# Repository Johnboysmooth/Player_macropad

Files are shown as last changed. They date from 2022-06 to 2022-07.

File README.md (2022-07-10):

# Player! V1.2

Player! is a five button macropad originally designed to accomodate changing music settings in Spotify without tabbing into the Spotify client. By default it is programmed to use the built-in media keys in Windows, which can be further optimised with global hotkeys using [Toastify](https://github.com/aleab/toastify).

Using four cherry compatible switches, Player! provides dedicated keys for pausing/playing music -  returning to a previous song, and skipping to the next song. The fourth switch remains user programmable, binded to 'insert' by default to be used as dedicated Discord mute key. A rotary encoder allows for volume control, with a toggle function bound to its embedded switch to allow rotary control of rewinding and fast-forwarding music.
# Images
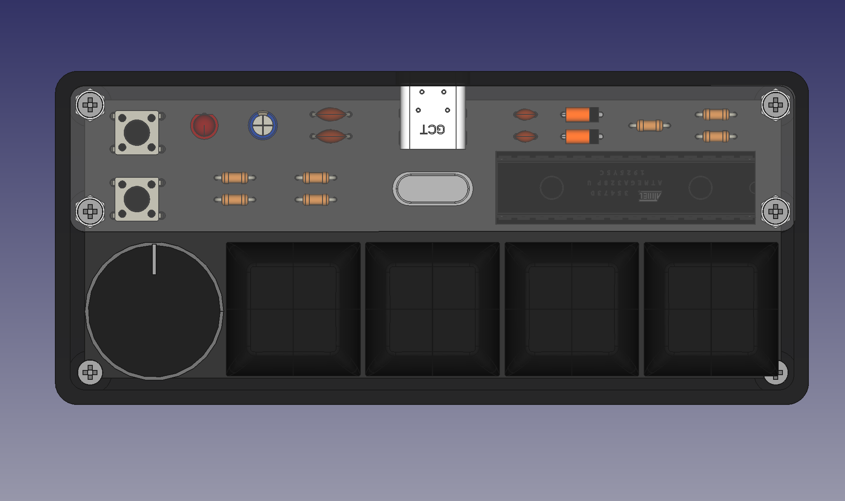
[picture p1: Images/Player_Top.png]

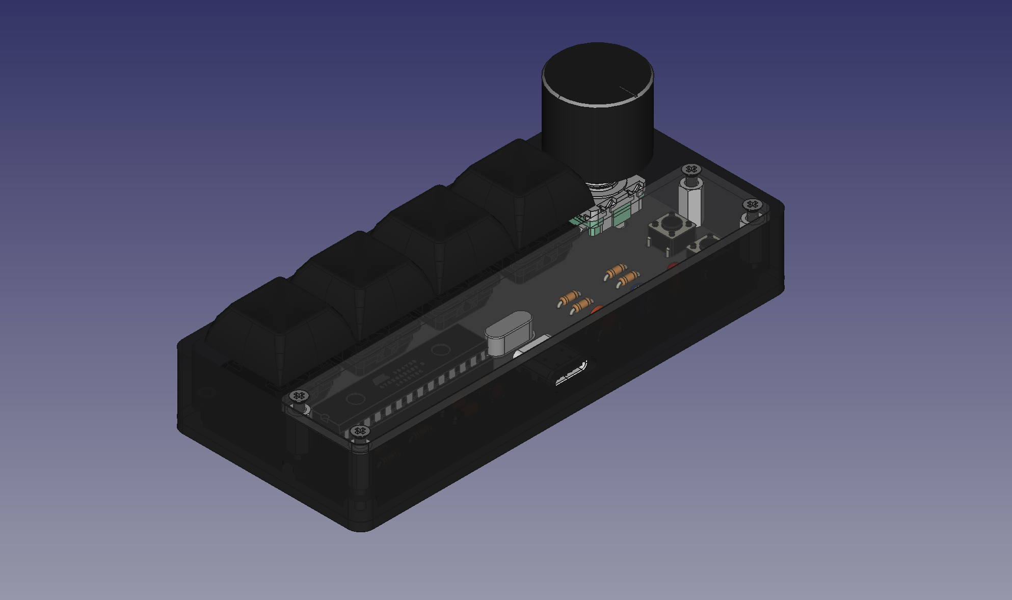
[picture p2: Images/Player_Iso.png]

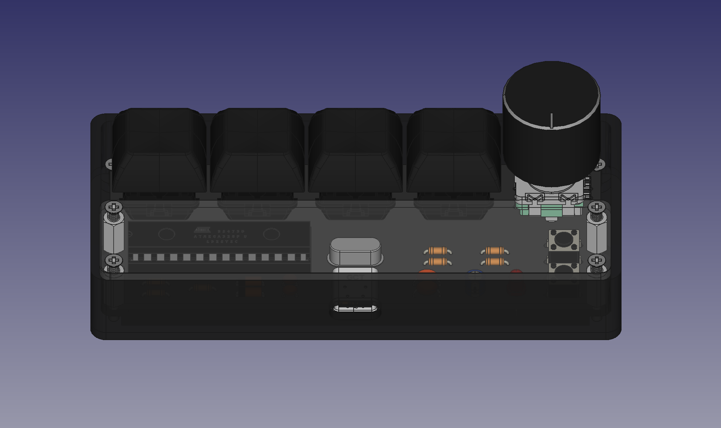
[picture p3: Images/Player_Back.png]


# [Bill of Materials](https://octopart.com/bom-tool/iGNVRgwb)

# Bootloader Information

The Player! uses a usb bootloader which allows the ATMega328 to program itself with QMK, namely USBaspLoader.

The custom bootloader was adapted from [coseyfannitutti](https://github.com/coseyfannitutti)'s, changing a few pin definitions, programmer choice and adding a port definiton for avrdude in my setup. 

* The bootloader is available [here](https://github.com/Johnboysmooth/USBaspLoader).
* The instructions for setting up the build environment can be found in the readme.
* Some changes may be required, such as changing the port or programmer definitions for your setup, which can be found on lines 9 and 44 of the makefile.inc respectively. **Never** edit the makefile directly.
* Flashing the ATMega328 once the build environment is setup:

	```make flash``` (flashes the makefile)

	```make fuse``` (sets fuses for ATMega328)

Assuming the flash was successful, it should now be possible to return the microcontroller to the Player! PCB and flash the firmware via the USB connection.

# Firmware 
Player! supports either [Vial](https://get.vial.today/) or [VIA](https://www.caniusevia.com/) for rebinding keys. It is recommended to use Vial to allow rebinding of the rotary encoder, and avoid additional steps required in VIA.

### Entering bootloader mode
Player! will need to be put into bootloader mode to allow QMK to be flashed via the USB connection, see below:

1. Press and hold ```Boot``` switch
2. Tap ```Reset``` switch
3. Release ```Boot``` switch

USBaspLoader will show up in device manager or as a connected device in QMK toolbox when the device has successfully entered bootloader mode, like so:
![](/Images/QMK_Toolbox.png)

## Vial Support (Recommended)

Vial compatible firmware can be flashed to the Player! using the [player_vial.hex](/Firmware). 
1. In QMK_Toolbox, click "Open", then navigate to player_vial.hex and select it. 
2. Click "Flash". 
3. Following successful flash completion, press the ```Reset``` button on the PCB. 

The Player! can now be configured and is now ready to use. The rotary encoder is rebound using the two circular icons on the top row.

*A current bug means the second layer is incorrectly labelled, however it maintains functionality.

### VIA Support (Not Recommended)

VIA compatible firmware can also be flashed to the Player! using the [player_via.hex](/Firmware), however an additional step is required.
1. In QMK_Toolbox, click "Open" then navigate to player_vial.hex and select it.
2. Click "Flash". 
3. Following successful flash completion, press the ```Reset``` button on the PCB. 
4. After opening the VIA window, navigate to the "Design" tab (which may require enabling in settings) and upload the playerkeymap.json. 

Going back to the Configure tab in VIA, the Player! can be configured and is now ready to use.

### Default Configuration

It is not required to use Vial or VIA when using the Player!, the default keymap can be flashed using the [player_default.hex](/Firmware). 
1. In QMK_Toolbox, click "Open" and navigate to player_default.hex and click "Flash".
2. Following successful flash completion, press the ```Reset``` button on the PCB. 

The Player! is now ready to use.

## License
<br />Player! is licensed under a <a rel="license" href="http://creativecommons.org/licenses/by-nc/4.0/">Creative Commons Attribution-NonCommercial 4.0 International License </a>

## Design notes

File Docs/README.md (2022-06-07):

# 3D Model Sources
[Keyswitch](https://www.snapeda.com/parts/MX1A-E1NW/Cherry/view-part)

[Rotary Encoder](https://grabcad.com/library/rotary-encoder-6)

[USB4085-GF-A](https://www.snapeda.com/parts/USB4085-GF-A/Global%20Connector%20Technology/view-part)

All other models are native to KiCad

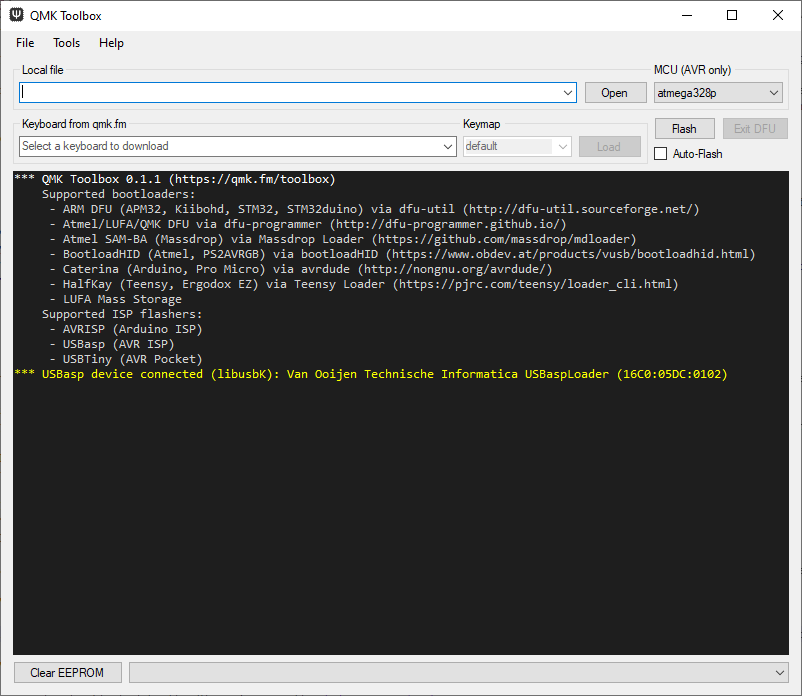
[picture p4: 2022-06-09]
Images/QMK_Toolbox.png

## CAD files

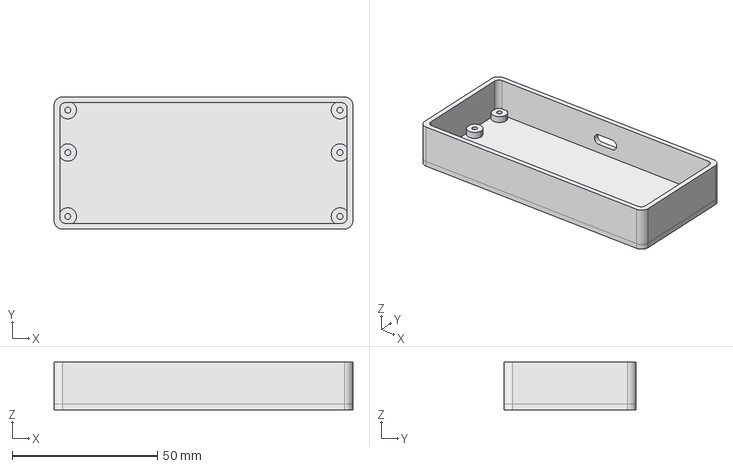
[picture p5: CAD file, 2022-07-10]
Case/Case.FCStd
103.0 x 45.6 x 16.4 mm

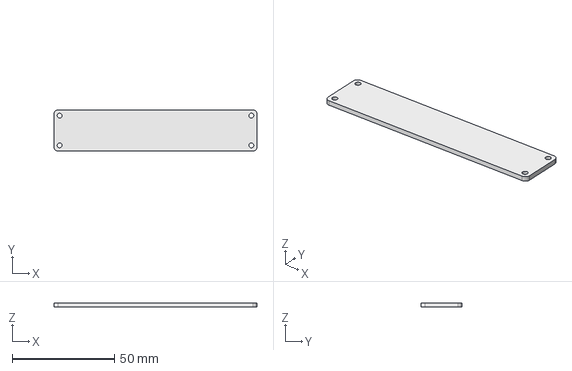
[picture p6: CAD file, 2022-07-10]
Case/Clear Top.FCStd
99.2 x 20.1 x 2.00 mm

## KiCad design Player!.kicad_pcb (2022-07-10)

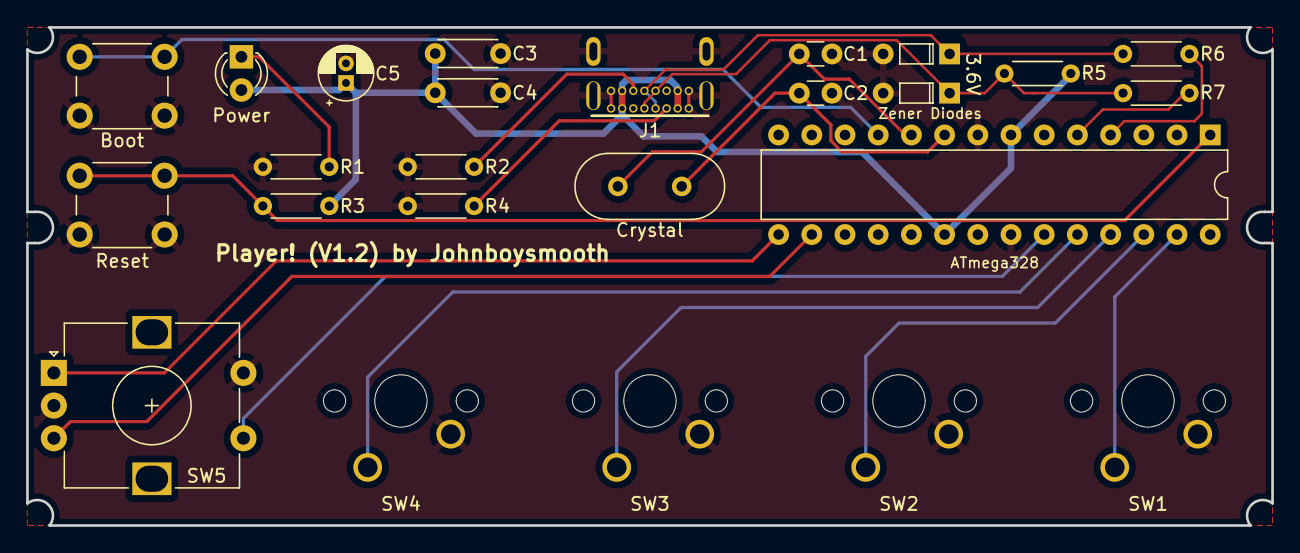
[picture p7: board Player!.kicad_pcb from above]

Board: 2 copper layers, 95.2 x 38.1 mm, 25 parts (0 on the bottom side), 20 nets.

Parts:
ATmega328: ATmega328P-P; ATmega328p DIP-28
Boot: BOOT; SW_PUSH_6mm
C1, C2: 22p; C_Disc_D3.0mm_W1.6mm_P2.50mm
C3, C4: 0.1u; C_Disc_D4.3mm_W1.9mm_P5.00mm
C5: 4.7u; CP_Radial_D4.0mm_P1.50mm
Crystal1: Crystal; Crystal_HC49-4H_Vertical
DN1: 3.6V; D_DO-35_SOD27_P5.08mm_Horizontal
DP1: 3.6V; D_DO-35_SOD27_P5.08mm_Horizontal
J1: USB4085-GF-A_REVA4; GCT_USB4085-GF-A_REVA4
Power: POWERLED; LED_D3.0mm
R1: 1.5k; R_Axial_DIN0204_L3.6mm_D1.6mm_P5.08mm_Horizontal
R2, R4: 5.1k; R_Axial_DIN0204_L3.6mm_D1.6mm_P5.08mm_Horizontal
R3: 10K; R_Axial_DIN0204_L3.6mm_D1.6mm_P5.08mm_Horizontal
R5: 1.5K; R_Axial_DIN0204_L3.6mm_D1.6mm_P5.08mm_Horizontal
R6, R7: 75; R_Axial_DIN0204_L3.6mm_D1.6mm_P5.08mm_Horizontal
Reset: RESET; SW_PUSH_6mm
SW1, SW2, SW3, SW4: SW_Push; Player! 1u PCB
SW5: RotaryEncoder_Switch; RotaryEncoder_Alps_EC12E-Switch_Vertical_H20mm

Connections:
+5V: ATmega328.7 (VCC), ATmega328.20 (AVCC), C3.1, C4.1, C5.1, J1.A4 (VBUS), J1.A9 (VBUS), J1.B4 (VBUS), J1.B9 (VBUS), Power.2 (A), R3.1, R5.1
/BOOT: ATmega328.11 (PD5), Boot.1
/CC1: J1.A5 (CC1), R4.1
/CC2: J1.B5 (CC2), R2.1
/DN: DP1.1 (K), J1.A7 (DN1), J1.B7 (DN2), R5.2, R7.1
/DP: DN1.1 (K), J1.A6 (DP1), J1.B6 (DP2), R6.1
/LED: Power.1 (K), R1.1
/RST: ATmega328.1 (~RESET/PC6), R3.2, Reset.1
/XTAL1: ATmega328.9 (XTAL1/PB6), C2.1, Crystal1.2
/XTAL2: ATmega328.10 (XTAL2/PB7), C1.1, Crystal1.1
D+: ATmega328.4 (PD2), R6.2
D-: ATmega328.5 (PD3), R7.2
GND: ATmega328.8 (GND), ATmega328.22 (GND), Boot.2, C1.2, C2.2, C3.2, C4.2, C5.2, DN1.2 (A), DP1.2 (A), J1.A1 (GND), J1.A12 (GND), J1.B1 (GND), J1.B12 (GND), J1.P1 (SHELL), J1.P2 (SHELL), J1.P3 (SHELL), J1.P4 (SHELL), R1.2, R2.2, R4.2, Reset.2, SW1.2, SW2.2, SW3.2, SW4.2, SW5.C, SW5.S1
ROTA: ATmega328.15 (PB1), SW5.A
ROTB: ATmega328.16 (PB2), SW5.B
SW1: ATmega328.27 (PC4), SW1.1
SW2: ATmega328.26 (PC3), SW2.1
SW3: ATmega328.25 (PC2), SW3.1
SW4: ATmega328.24 (PC1), SW4.1
SW5: ATmega328.23 (PC0), SW5.S2

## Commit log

2022-06-02 Player! Macropad
    Schematics, PCB and Footprints
    [Player!.kicad_pcb, Player!.kicad_sch]
2022-06-02 Minor Changes for V1.1
    Altered encoder location, some minor changes to front silkscreen texts
    [Player!.kicad_pcb]
2022-06-02 Minor text changes
    [Player!.kicad_sch]
2022-06-07 3D Models
    Added models missing for various components, rotated PCB and text. Updated readme with images
    [Player!.kicad_pcb]
2022-06-07 Changed Rotary Encoder Model
    [Player!.kicad_pcb]
2022-06-07 Repositioned LED
2022-06-08 Updated diode on 3d model
    [Player!.kicad_pcb]
2022-06-08 Updated images with fixed diode
2022-06-09 Update readme for rotary encoder in Vial
2022-06-09 Update PCB
    Updated the PCB to include new models for rotary encoder with cap, cherry keys with keycaps. Also reordered some components and added a new horizontal zener diode model
    [Player!.kicad_pcb, Player!.kicad_sch]
2022-06-09 Add bill of materials
2022-06-09 Fix text location
    [Player!.kicad_sch]
2022-06-09 Update text position
    [Player!.kicad_pcb]
2022-06-15 Updated Models
    Changed type C footprint & model, updated to use .step models in 3d for all components
    [Player!.kicad_pcb, Player!.kicad_sch]
2022-07-10 Updating PCB and Models for Case
    [Player!.kicad_pcb, Player!.kicad_sch]
2022-07-10 Adding Case Models
    [Case.FCStd, Clear Top.FCStd]
2022-07-10 Updating Images with Case
